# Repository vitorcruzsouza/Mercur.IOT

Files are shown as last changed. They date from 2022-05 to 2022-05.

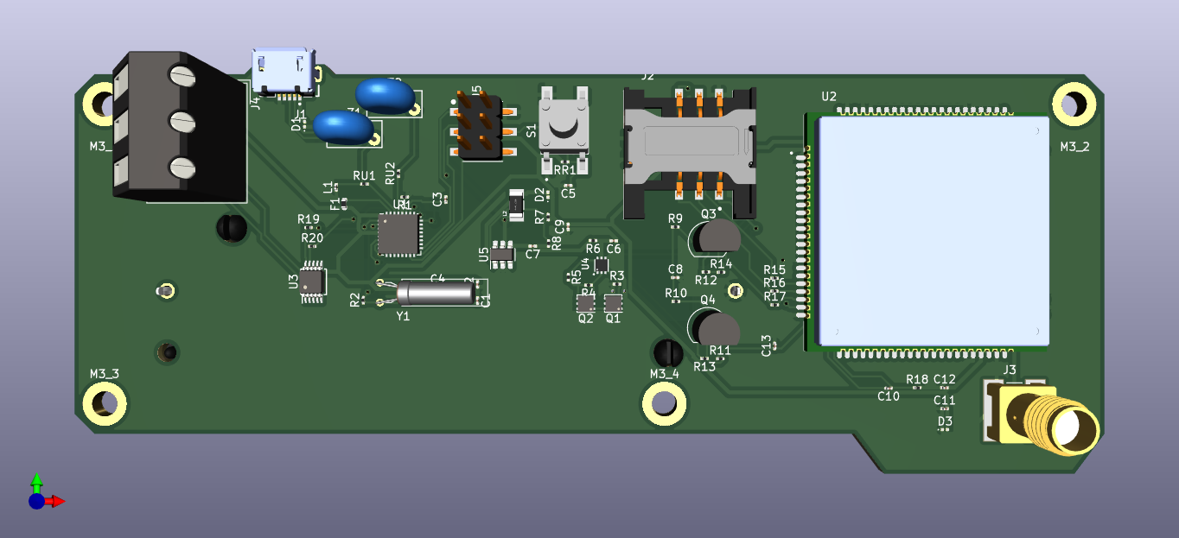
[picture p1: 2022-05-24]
docs/PCB_3D_top.png

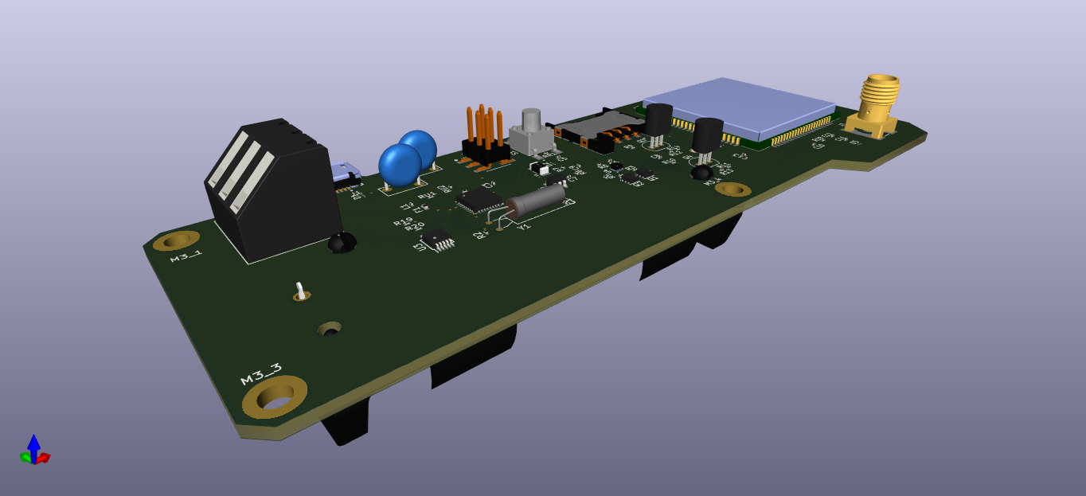
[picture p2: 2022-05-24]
docs/PCB_3D_isometric.png

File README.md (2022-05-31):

EN-US: This content was written in both English and Portuguese. To access content in English, [clique here](#enus)

PT-BR: Este conteúdo foi escrito em Inglês e em Português. Para acessar o conteúdo em Português, [clique aqui](#ptbr)

---

# EN/US
# MercurIOT - Sensor Data Transmitter via GSM
readme v1.6

## Contents

<!-- toc -->

- [1. Description](#description)
  - [Objective](#objective)
  - [Behind the name](#behind-the-name)
- [2. Plataform](#platform)
  - [Conceptualization - Electronics](#conceptualization---electronics)
  - [Conceptualization - Code](#conceptualization---code)
  - [Technical Specifications](#technical-specifications)
  - [Bill of Materials](#bill-of-materials)
- [3. Circuit Schematic](#circuit-schematic)
  - [Full System](#full-system)
  - [Power Supply](#power-supply-and-battery-charging)
  - [Microcontroller](#microcontroller)
  - [GSM Communication](#gsm-communication)
  - [Sensor 16-bit ADC](#sensor-16bit-adc)
- [4. Printed Circuit Board (PCB)](#printed-circuit-board-pcb)
  - [2D Visualization of All Layers](#2d-visualization-of-all-layers)
  - [2D Visualization of Top Layer](#2d-visualization-of-top-layer)
  - [2D Visualization of Bottom Layer](#2d-visualization-of-bottom-layer)
- [5. 3D Render of the PCB](#3d-render-of-the-pcb)
  - [Top View](#top-view)
  - [Bottom View](#bottom-view)
  - [Isometric View](#isometric-view)

- [About me](#about-me)

<!-- tocstop -->

## Description

#### Objective
Fully developing a wireless data transmission solution for industrial applications, capable of sending 500kB of sensing data remotely to be used in machine operation conditions monitoring.

The scope of this project encopasses the development of both the PCB and firmware required for operation of the microcontrollers utilized.

#### Behind the name
Inspired by the greek god Mercury, son of Zeus and messenger of the gods, MercurIOT was developed with the purpose of delivering a flexible platform, upon which multiple IOT communication solutions can be created.

## Platform 

### Conceptualization - Electronics:

To send sensor information to a distant receiver, the **GSM tecnology** was selected - the same used for 3G/4G mobile data plans - due to the ease of access to nacional brazillian infrastructure to mobile network systems (where this project was conceived), thus high capacity for long distance tranmissions.

Therefore, the **SIM7600EH** GSM communication chip was chosen, since it presents an easy to use yet powerful list of commands, high market availability and broad documentation.

For controlling the whole system and being responsible for converting the sensor data into commands the SIM7600 can understand, the Atmel **ATMEGA8U2-MU** was selected as a suitable microcontroller. Aside from having very broad documentation and market availability for being one the chips used by Arduino boards, the ATMEGA8 is specially handy for having integrated USB communication, simplifying the final board layout. Its 16MHz clock shall be sufficient to execute all of the communication with no major delays.

One of the limitations of the ATMEGA8, however, is the relatively low resolution of its ADC (Analog to Digital Converter chip), which has a 10 bit resolution (maximum of 1024 individual values in any readings). Therefore, an accompanying **ADS1115** chip was selected to improve the data quality the MercurIOT board can supply. This IC has a 16 bit resolution (max. 65,536 values) for analog readings, it can communicate in I2C protocol with other chips in its network, and can support up to 4 individual analog inputs. For this project, however, we're only going to use one.

Finally, to power the whole system, a **18650 Lithium-Ion** cell was selected, since this type of battery chemistry is very common and is currently one of the best options on Power Density to Price and/or size. Utilizing Li-Ion cells in this project allows it to be recharged, but adds a degree of complexity by requiring some battery monitoring and protection features. For this, the **BQ29707DSET** battery management IC is being used (features include overcharge protection, overdischarge protection, overcurrent protection) in conjunction with the **MT3608** boost-converter for stabilizing a 5VDC supply rail to all other electronics.

### Conceptualization - Code:

To construct a wireless transmission solution, there are a few major things that have to be considered. The first is what information is going to be sent, the second is how it is going to be sent, and third but not least how it is going to be interpreted by what's receiving it.

This way, the first problem that need to be tackled is the **information source** itself. In this project, for demonstration purposes, a hypothetical, unspecified, pre-amplified analog sensor is going to be used, as this is encopasses almost any type of application that telemetry sensors can be used in, since most physical quantity sensing devices output analog (voltage or current) signals.

Since a 16-bit capabe Analog to Digital Converter (ADC) is being used to capture these sensed signals, these 16-bit values have to be processed accordingly. For that, the Adafruit_ADS1015.h library is used, to facilitate I2C communication between the microcontroller and the ADC unit and to interpret the information.

Assuming a server is going to receive sensed data and utilize it, this processed information need to be sent via some medium. For this, the SIM7600EH chip has a list of GSM commands to perform varying tasks. If sent from the microcontroller to the GSM IC via serial UART communication, these commands will each perform an action through the 3G/4G communication line. [Here's a full list of AT commands and instructions on how to use them here.](https://usermanual.wiki/Document/SIM7500SIM760020SeriesAT20Command20ManualV107.443047306/html)

The information that is going to be transmitted, however, needs to be encoded in a certain protocol, so that both parties of this system - client (transmitter) and server (receiver) - can understand what is being relayed; and more critically, know what to do with each information given.

For this, the MQTT (Message Queuing Telemetry Transport) is used. It is a protocol based on TCP/IP network communication that simplifies parallel data transmission between multiple parties, specially for IoT applications such as this one, while providing a light and simple framework for less powerful devices to run on. [Read this for more information on how the MQTT protocol works.](https://randomnerdtutorials.com/what-is-mqtt-and-how-it-works/)

Joining the AT (GSM) and MQTT communication formats, we can compile the data collected by whichever sensor is plugged into the MercurIOT transmitter, and send it to a MQTT topic dedicated to captured sensor data, which then can be subscribed to by any software or BI (Business Inteligence) suite that whishes to utilize or display that information.

### Technical Specifications

#### Electronics

##### Control
- Microcontrolador: ATmega8U2-MU
- IC USB Communication: ATmega8U2-MU
- IC GSM Communication: SIM7600E-H
##### Power supply
- IC Battery Management: BQ29707DSET
- IC Voltage Regulator: MT3608
- Battery: Li-Ion 18650 cell
##### Sensing
- IC 16-bits Analog-Digital Converter: ADS1115

#### Code
- Library Adafruit_ADS1015.h (for I2C communication with the 16bit ADC)
- Library SoftwareSerial.h (for serial UART communication with the GSM and MQTT)
- Libraries Arduino.h, Wire.h e ArduinoLowPower.h (for using the native Arduino platform functionalities)
##### Software
- Development Environment: VSCode
- Platform: Plaform.io

### Bill of Materials

[Link to the Bill of Materials file, complete with links for ordering the parts used globally.](https://github.com/vitorcruzsouza/Mercur.IOT_TRACTIAN/blob/main/docs/BOM.md)

## Circuit Schematic
[Link to folder with circuit and PCB ECAD files.](https://github.com/vitorcruzsouza/Mercur.IOT_TRACTIAN/tree/main/hardware_sch/Mercurio_wirelessTransmitter)

### Full System
[Link to the full schematic file.](https://github.com/vitorcruzsouza/Mercur.IOT_TRACTIAN/blob/main/docs/Mercurio_SCHEMATIC-SHEET.pdf)
circuit_fullTransmitter

### Power Supply and Battery Charging
circuit_powerSupply

The circuit above utilizes a BQ2970 battery management IC to monitor the lithium-ion battery's voltage and offer multiple protections. By utilizing a selection of multiple internal comparators, the IC monitors the voltage coming from the positive side of the battery through the "BAT" pin 5. Either when the voltage is too high (±4.2V), too low (±3.4V) or the current is too high (overcurrent or short-circuit), the IC deactivates of its "COUT" or "DOUT" outputs to disconnect the battery's negative side to Ground, through its two CSD16301Q2 MOSFET switches.

Through the use of the MT3608 boost converter IC, both the battery's and the USB port's voltage are steped-up and regulated to 5VDC, for supplying both the ATMEGA and the SIM7600 chips. By using a zener diode between the USB port and the battery, as well as one between the boost converter an all of the componentes supplied, the circuit can be both powered on by the USB port and charge the battery simultaneously without causing a power loop.

### Microcontroller
circuit_microcontroller

Together with the microcontroller are a couple of passive components to allow its basic functioning, like a 16MHz clock crystal and accompanying oscillating capacitors, varistors for USB power protection and a ferrite bead for filtering, a 500mA fuse between the power circuit and the VCC port of the ATMEGA chip, a RESET button and 6 open pins (ICSP) for connecting configuration signals, such as boot loading and resetting once again.

### GSM Communication
circuit_GSM

In this schematic, two S8050 transistors can be observed in series with the TXD and RXD transmission lines that are used to connect the SIM7600E-H and the ATMEGA8U-MU via UART. This is used to decouple both chips while no data is being transmitted, since the very TXD and RXD lines activate the transistors that let the data bits pass, so that these wires do not act as antennas and pickup any interference, stopping any of the two ICs accidentally interpret noise as information.

Pins 17 - 20 are connected to the SIM card slot and therefore the SIM card inserted, and pin 82 is connected to a SMA antenna connector, so that any type or size of antenna desired can be used.

The "PWRKEY" and "RESET" are pulled to ground so that the IC is always active. One improvement this circuit design could benefit from is having the microcontroller, via a switching device, have the option to activate or deactivate both the Reset and Power-Key pins so that the IC can be rebooted or turned off completely for power saving measures.

### Sensor 16bit ADC
circuit_ADC

Last but not least, the ADS1115 16-bit ADC is connected to the SCL and SCA pins of the ATMEGA microcontroller, through which the ADC relays the sensed analog  signals through I2C serial communication. The sensor, whichever one may be chosen for the application, can be connected to the J4 screw terminal following the "VCC, Signal, GND" pinout standard.

## Printed Circuit Board (PCB)

### 2D Visualization of All Layers
PCB_2D_all-layers

For information all data lines excluding the antenna line, the traces were set to 10 mils (0.254 mm). For all other lines (power lines and antenna), the traces were set to 20 mils (0.5 mm), so that a maximum of 1.5 A can be supplied to all components and used for more power-intensive LTE data transmission.

### 2D Visualization of Top Layer
PCB_2D_top-layer

### 2D Visualization of Bottom Layer
PCB_2D_bottom-layer

## 3D Render of the PCB

### Top View
PCB_3D_top

### Bottom View
PCB_3D_bottom

### Isometric View
PCB_3D_isometric

## About me

### Contact info:
<p>Vitor Cruz Souza<br>
São Paulo, SP, Brazil<br>
E-mail: vitor.cruz.souza.2001@gmail.com</p>

---

[Back to the top.](#contents)

---

# PT/BR
# MercurIOT - Transmissor de Dados de Sensor via GSM
readme v1.52

(Esta sessão ainda não foi totalmente traduzida).

## Conteúdos

<!-- toc -->

- [1. Descrição](#descrição)
  - [Objetivo](#objetivo)
  - [Por trás do nome](#por-trás-do-nome)
- [2. Plataforma](#plataforma)
  - [Conceitualização](#conceitualização)
  - [Especificações Técnicas](#especificações-técnicas)
  - [Lista de Materiais](#lista-de-materiais)
- [3. Esquemático do Circuito](#esquemático-do-circuito)
  - [Sistema Completo](#sistema-completo)
  - [Alimentação e Bateria](#alimentação-e-bateria)
  - [Microcontrolador](#microcontrolador)
  - [Comunicação GSM](#comunicação-gsm)
  - [ADC 16bits do Sensor](#adc-16bits-do-sensor)
- [4. Placa de Circuito Impresso (PCI)](#placa-de-circuito-impresso-pci)
  - [Visualização 2D de Todas as Camadas](#visualização-2d-de-todas-as-camadas)
  - [Visualização 2D da Camada Superior](#visualização-2d-da-camada-superior)
  - [Visualização 2D da Camada Inferior](#visualização-2d-da-camada-inferior)
- [5. Renderização 3D da PCI](#renderização-3d-da-pci)
  - [Vista Superior](#vista-superior)
  - [Vista Inferior](#vista-inferior)
  - [Vista Isométrica](#vista-isométrica)

- [Sobre mim](#sobre-mim)

<!-- tocstop -->

## Descrição

#### Objetivo
O objetivo do projeto MercurIOT é desenvolver uma solução completa de transmissão de dados para aplicações industriais, capaz de enviar 500kB de dados de sensoriamento remotamente, a serem usados no monitoramento de condições de operação de máquinas.

O escopo deste projeto abriga o desenvolvimento de ambos PCI e firmware necessário para operação dos microcontroladores utilizados.

#### Por trás do nome
Inspirado no deus greco-romano Mercúrio, filho de Zeus e mensageiro dos deuses, o MercurIOT foi desenvolvido com o propósito de entregar uma plataforma flexível, sobre a qual múltiplas soluções de comunicação IOT possam ser criadas.

## Plataforma

### Conceitualização

Para realizar o envio de informações do sensor à distância, foi escolhido utilizar de tecnologia GSM, a mesma utilizada para comunicação 3G/4G em telefonia móvel, devido ao fácil acesso à infraestrutura nacional brasileira de redes móveis (onde este projeto foi concebido) e, portanto, alta capacidade de transmissão de dados à longas distâncias.

### Especificações Técnicas

#### Eletrônica

##### Controle
- Microcontrolador: ATmega8U2-MU
- CI Comunicação USB: ATmega8U2-MU
- CI Comunicação GSM: SIM7600E-H
##### Alimentação
- CI Gerenciamento de Baterias: BQ29707DSET
- CI Regulador de Tensão: MT3608
- Bateria: Li-Ion 18650
##### Sensoriamento
- CI Conversor Analógico Digital 16-bits: ADS1115

#### Código
- Biblioteca Adafruit_ADS1015.h (para comunicação I2C com o ADC de 16bits)
- Biblioteca SoftwareSerial.h (para comunicação serial UART com o GSM e MQTT)
- Bibliotecas Arduino.h, Wire.h e ArduinoLowPower.h (para uso de funcionalidades nativas da plataforma Arduino)

##### Software
- Ambiente de Desenvolvimento: VSCode
- Plataforma: Plaform.io

### Lista de Materiais

[Link para a Lista de Materiais contendo também links para compra internacional dos componentes usados.](https://github.com/vitorcruzsouza/Mercur.IOT_TRACTIAN/blob/main/docs/BOM.md)

## Esquemático do Circuito
[Link para pasta com arquivos ECAD do circuito e PCB.](https://github.com/vitorcruzsouza/Mercur.IOT_TRACTIAN/tree/main/hardware_sch/Mercurio_wirelessTransmitter)

### Sistema Completo
[Link para o arquivo do esquemático completo.](https://github.com/vitorcruzsouza/Mercur.IOT_TRACTIAN/blob/main/docs/Mercurio_SCHEMATIC-SHEET.pdf)
circuit_fullTransmitter

### Alimentação e Bateria
circuit_powerSupply

### Microcontrolador
circuit_microcontroller

### Comunicação GSM
circuit_GSM

### ADC 16bits do Sensor
circuit_ADC

## Placa de Circuito Impresso (PCI)
[Link para pasta com arquivos ECAD do circuito e PCB.](https://github.com/vitorcruzsouza/Mercur.IOT_TRACTIAN/tree/main/hardware_sch/Mercurio_wirelessTransmitter)

### Visualização 2D de Todas as Camadas
PCB_2D_all-layers

### Visualização 2D da Camada Superior
PCB_2D_top-layer

### Visualização 2D da Camada Inferior
PCB_2D_bottom-layer

## Renderização 3D da PCI

### Vista Superior
PCB_3D_top

### Vista Inferior
PCB_3D_bottom

### Vista Isométrica
PCB_3D_isometric

## Sobre mim

### Informações de contato:
<p>Vitor Cruz Souza<br>
São Paulo, SP, Brasil<br>
E-mail: vitor.cruz.souza.2001@gmail.com</p>

---

[Ir para o topo.](#conteúdos)

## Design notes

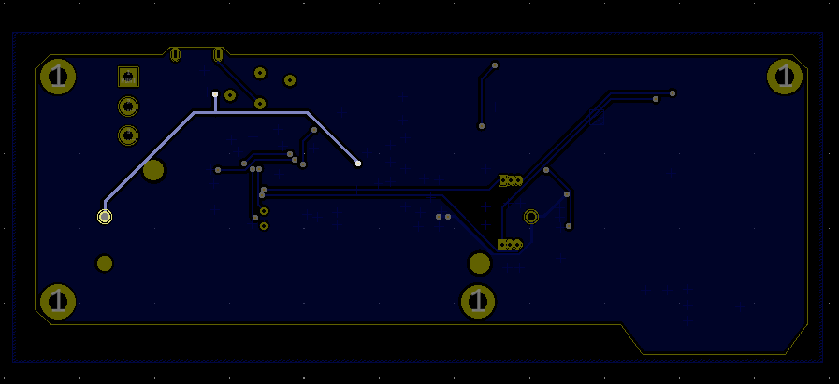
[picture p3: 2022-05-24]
docs/PCB_2D_bottom-layer.png

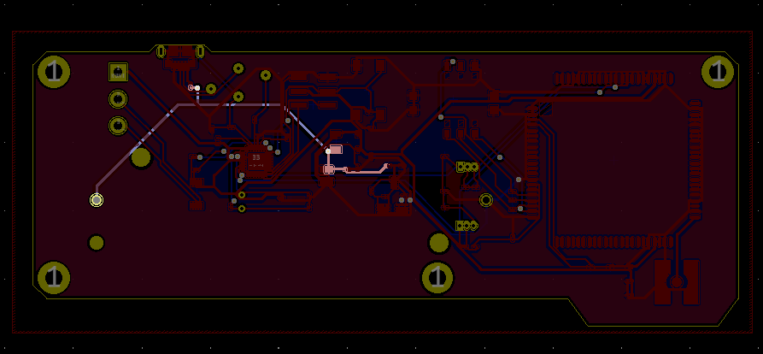
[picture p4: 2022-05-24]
docs/PCB_2D_all-layers.png

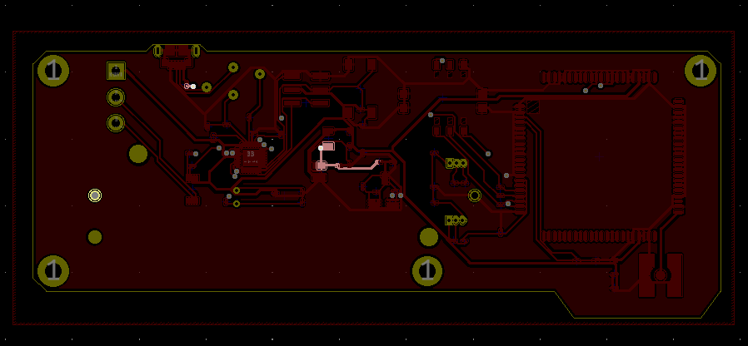
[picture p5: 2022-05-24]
docs/PCB_2D_top-layer.png

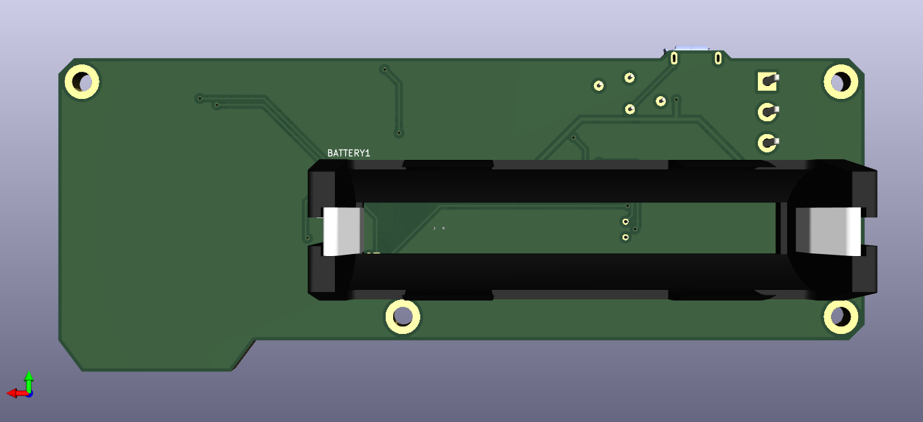
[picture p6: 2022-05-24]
docs/PCB_3D_bottom.png

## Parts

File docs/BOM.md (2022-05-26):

# Bill of Materials (BOM)

| Nº | COMPONENT                | PART Nº            | VALUE             | PACKAGE    | QTY | DESIGNATOR           | REFERENCE                                                                                                                                                                                     |
| Nº | COMPONENT                | PART Nº            | VALUE             | PACKAGE    | QTY | DESIGNATOR           | REFERENCE                                                                                                                                                                                     |
| -- | ------------------------ | ------------------ | ----------------- | ---------- | --- | -------------------- | ------ |
| 1  | Socket for 18650 Battery | 1043               | \-                | Custom     | 1   | BATTERY1             | https://www.mouser.com/ProductDetail/Keystone-Electronics/1043?utm\_campaign=mouser&qs=%2F7TOpeL5Mz6j%2FnxeOA1rsg%3D%3D&utm\_content=model&utm\_medium=online&utm\_source=snapedaonline       |
| 2  | Capacitor SMD            | LD033D105MAB2A     | 1uF               | SMD 0603   | 2   | C3, C13              | https://www.digikey.com/en/products/detail/kyocera-avx/LD033D105MAB2A/11235553?utm\_medium=aggregator&utm\_campaign=buynow&utm\_source=snapeda                                                |
| 3  | Capacitor SMD            | 885012206046       | 100nF             | SMD 0603   | 1   | C4                   | https://www.mouser.com/ProductDetail/Wurth-Elektronik/885012206046?utm\_medium=online&utm\_source=snapedaonline&utm\_content=model&utm\_campaign=mouser&qs=0KOYDY2FL2%252B89gr6HvTBXA%3D%3D   |
| 4  | Capacitor SMD            | C0603C104J4RACTM   | 0.1uF             | SMD 0603   | 5   | C5, C6, C8, C10, C11 | https://www.mouser.com/ProductDetail/KEMET/C0603C104J4RACTM?utm\_medium=online&utm\_source=snapedaonline&utm\_content=model&utm\_campaign=mouser&qs=dtFCtVqVXWcMSWNKXNx%2FXw%3D%3D            |
| 5  | Capacitor SMD            | C1608JB0J226M080AC | 22pF              | SMD 0603   | 2   | C1, C2, C7, C9       | https://www.mouser.com/ProductDetail/TDK/C1608JB0J226M080AC?utm\_medium=online&utm\_source=snapedaonline&utm\_content=model&utm\_campaign=mouser&qs=xLDY6iXSiQbnuIg2qX8hLQ%3D%3D              |
| 6  | Capacitor SMD            | 06033A330KAT2A     | 33pF              | SMD 0603   | 1   | C12                  | https://www.mouser.com/ProductDetail/Kyocera-AVX/06033A330KAT2A?utm\_campaign=mouser&qs=3M9tbN%252BqtAY8x5rz2c8b4A%3D%3D&utm\_content=model&utm\_medium=online&utm\_source=snapedaonline      |
| 7  | Diode SMD                | MMSZ5221B          | \-                | SOD-123F   | 3   | D1-D3                | https://www.digikey.com/en/products/detail/taiwan-semiconductor-corporation/MMSZ5221B-RHG/7374840?utm\_medium=aggregator&utm\_campaign=buynow&utm\_source=snapeda                             |
| 8  | Fuse SMD                 | 0603L050SLYR       | 500mA             | SMD 0603   | 1   | F1                   | https://www.mouser.com/ProductDetail/Littelfuse/0603L050SLYR?utm\_medium=online&utm\_campaign=mouser&qs=%252BPPFKVzHyALE6NerVow6aQ%3D%3D&utm\_content=model&utm\_source=snapedaonline         |
| 9  | Connector USB Micro B    | USB3075-30-A       | \-                | SMD        | 1   | J1                   | https://www.mouser.com/ProductDetail/GCT/USB3075-30-A?utm\_campaign=mouser&qs=KUoIvG%2F9IlbGMJplbp1ybA%3D%3D&utm\_content=model&utm\_medium=online&utm\_source=snapedaonline                  |
| 10 | Socket for SIM Card      | 693010020611       | \-                | SMD        | 1   | J2                   | https://www.mouser.com/ProductDetail/Wurth-Elektronik/693010020611?utm\_campaign=mouser&qs=E2PpAYvlWVtRUX051C0QBA%3D%3D&utm\_content=model&utm\_medium=online&utm\_source=snapedaonline       |
| 11 | Socket for SMA Antenna   | CONSMA001          | \-                | THT        | 1   | J3                   | https://www.mouser.com/ProductDetail/Linx-Technologies/CONSMA001?utm\_medium=online&utm\_source=snapedaonline&utm\_content=model&utm\_campaign=mouser&qs=K5ta8V%252BWhtZcWpGVLKOC5A%3D%3D     |
| 12 | Terminal Block 1x3 5mm   | 30602              | \-                | THT        | 1   | J4                   | https://www.mouser.com/ProductDetail/Altech/30.602?qs=6YwAVAdATLxlHE0VSugUBQ%3D%3D                                                                                                            |
| 13 | Connector Header 6 Pins  | 61000621121        | \-                | THT        | 1   | J5                   | https://www.mouser.com/ProductDetail/Wurth-Elektronik/61000621121?utm\_campaign=mouser&qs=PhR8RmCirEYoFU9UUO%252Bbug%3D%3D&utm\_content=model&utm\_medium=online&utm\_source=snapedaonline    |
| 14 | Ferrite Bead SMD         | BLM21BD222TZ1D     | 2.2k Ohm 100MHz   | SMD 0603   | 1   | L1                   | https://www.mouser.com/ProductDetail/Murata-Electronics/BLM21BD222TZ1D?utm\_medium=online&utm\_source=snapedaonline&utm\_content=model&utm\_campaign=mouser&qs=lEfY3O89AqmiyVVAo6%2F2iA%3D%3D |
| 15 | Inductor SMD             | AIML-1206-120K-T   | 12uH              | SMD 1206-2 | 1   | L2                   | https://www.digikey.com/en/products/detail/abracon-llc/AIML-1206-120K-T/2663044?utm\_campaign=buynow&utm\_medium=aggregator&utm\_source=snapeda                                               |
| 16 | MOSFET N-channel         | CSD16301Q2         | \-                | WSON-6     | 2   | Q1, Q2               | https://www.mouser.com/ProductDetail/Texas-Instruments/CSD16301Q2?utm\_campaign=mouser&qs=6eIRK1XQNPbc2iRancB5Tw%3D%3D&utm\_content=model&utm\_medium=online&utm\_source=snapedaonline        |
| 17 | Transistor BJT NPN       | SS8050CTA          | \-                | TO-92      | 2   | Q3, Q4               | https://www.mouser.com/ProductDetail/onsemi-Fairchild/SS8050CTA?qs=UMEuL5FsraCvGU9pAIJ0vg%3D%3D                                                                                               |
| 18 | Resistor SMD             | MCT0603MD1004BP500 | 1M Ohm            | SMD 0603   | 1   | R1                   | https://www.mouser.com/ProductDetail/Vishay/MCT0603MD1004BP500?qs=Jslch3jnSjlxqHB2XifrNA%3D%3D                                                                                                |
| 19 | Resistor SMD             | CMP0603AFX-27R0ELF | 27 Ohm            | SMD 0603   | 1   | R2                   | https://www.mouser.com/ProductDetail/Bourns/CMP0603AFX-27R0ELF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                                                                              |
| 20 | Resistor SMD             | CR0603-JW-515ELF   | 5.1M Ohm          | SMD 0603   | 2   | R3, R4               | https://www.mouser.com/ProductDetail/Bourns/CR0603-JW-515ELF?qs=tknLyCMIRbNISwUtBrYwDA%3D%3D                                                                                                  |
| 21 | Resistor SMD             | CR0603-FX-2201ELF  | 2.2k Ohm          | SMD 0603   | 1   | R5                   | https://www.mouser.com/ProductDetail/Bourns/CR0603-FX-2201ELF?qs=zx2075yZkZKUzLkJq4yLqg%3D%3D                                                                                                 |
| 22 | Resistor SMD             | CMP0603-FX-3300ELF | 330 Ohm           | SMD 0603   | 1   | R6                   | https://www.mouser.com/ProductDetail/Bourns/CMP0603-FX-3300ELF?qs=TiOZkKH1s2TCw5ua2N2IJg%3D%3D                                                                                                |
| 23 | Resistor SMD             | CR0603-FX-2200ELF  | 220 Ohm           | SMD 0603   | 1   | R7                   | https://www.mouser.com/ProductDetail/Bourns/CR0603-FX-2200ELF?qs=zx2075yZkZJIjTIaFPYl8g%3D%3D                                                                                                 |
| 24 | Resistor SMD             | RCS060330R0FKEA    | 30 Ohm            | SMD 0603   | 1   | R8                   | https://www.mouser.com/ProductDetail/Vishay-Dale/RCS060330R0FKEA?qs=HalnxurKHBvY2IbBct5T7Q%3D%3D                                                                                              |
| 25 | Resistor SMD             | CRCW06034K70FKEAHP | 4.7k Ohm          | SMD 0603   | 2   | R9-R14               | https://www.mouser.com/ProductDetail/Vishay-Dale/CRCW06034K70FKEAHP?qs=k2%2FDWSARqgF9tclCHvhGkQ%3D%3D                                                                                         |
| 26 | Resistor SMD             | CHP0603AJW-220ELF  | 22 Ohm            | SMD 0603   | 4   | R15-R17, RU1, RU2    | https://www.mouser.com/ProductDetail/Bourns/CHP0603AJW-220ELF?qs=GedFDFLaBXEEl5eoX7Ig7w%3D%3D                                                                                                 |
| 27 | Resistor SMD             | CHP0603AFX-1001ELF | 1k Ohm            | SMD 0603   | 1   | R18                  | https://www.mouser.com/ProductDetail/Bourns/CHP0603AFX-1001ELF?qs=BJlw7L4Cy79wF3rZ%2FmXmqQ%3D%3D                                                                                              |
| 28 | Resistor SMD             | RCA060310K0FKEAHP  | 10k Ohm           | SMD 0603   | 3   | R19, R20, RR1        | https://www.mouser.com/ProductDetail/Vishay-Draloric/RCA060310K0FKEAHP?qs=rrS6PyfT74co7hzD7IqH8w%3D%3D                                                                                        |
| 29 | Switch SPST              | 5-1437565          | \-                | SMD        | 1   | S1                   | https://www.mouser.com/ProductDetail/Microchip-Technology/ATMEGA8U2-MU?qs=JV7lzlMm3yIasmzHjSeQNw%3D%3D                                                                                        |
| 30 | ATMEGA8 Microcontroller  | ATMEGA8U2-MU       | \-                | QFN-32     | 1   | U1                   | https://www.mouser.com/ProductDetail/Microchip-Technology/ATMEGA8U2-MU?qs=JV7lzlMm3yIasmzHjSeQNw%3D%3D                                                                                        |
| 31 | SIM7600 GSM IC           | SIM7600E-H         | \-                | Tray       | 1   | U2                   | https://www.digikey.com/en/products/detail/simcom-wireless-solutions-limited/SIM7600E-H/15841468?utm\_campaign=buynow&utm\_medium=aggregator&utm\_source=snapeda                              |
| 32 | ADS1115 ADC IC           | ADS1115IDGS        | \-                | VSSOP-10   | 1   | U3                   | https://www.mouser.com/ProductDetail/Texas-Instruments/ADS1115IDGSR?utm\_campaign=mouser&qs=IK5e5L0zOXjKCJoVMhYO%2FQ%3D%3D&utm\_content=model&utm\_medium=online&utm\_source=snapedaonline    |
| 33 | Battery Management IC    | BQ29707DSET        | \-                | WSON-6     | 1   | U4                   | https://www.mouser.com/ProductDetail/Texas-Instruments/BQ29707DSET?qs=7z%252BmIopC6%2FK8PFHAGER5Bg%3D%3D                                                                                      |
| 34 | Boost Converter IC       | MT3608             | \-                | SOT-23-6   | 1   | U5                   | https://lcsc.com/product-detail/DC-DC-Converters\_XI-AN-Aerosemi-Tech-MT3608\_C84817.html                                                                                                     |
| 35 | Crystal                  | AB308-16.000MHZ    | 16MHz             | THT        | 1   | Y1                   | https://www.mouser.com/ProductDetail/ABRACON/AB308-16.000MHZ?qs=GgB7MJ%2FTIsRBoegjtNv69g%3D%3D                                                                                                |
| 36 | Varistor                 | B72207S1390K201    | 50VDC 1.2kA 900pF | THT        | 2   | Z1, Z2               | https://www.mouser.com/ProductDetail/EPCOS-TDK/B72207S1390K201?qs=dEfas%2FXlABKmh0iq2keXQQ%3D%3D                                                                                              |

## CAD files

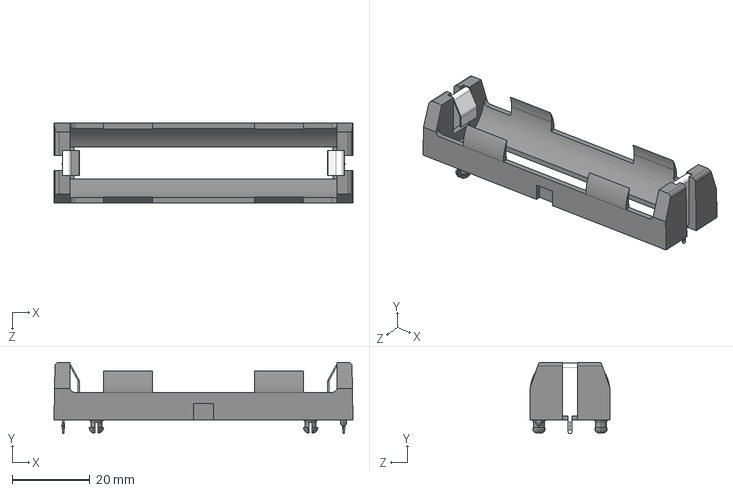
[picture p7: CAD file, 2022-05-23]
hardware_libs/1043/1043.step
77.1 x 18.4 x 20.7 mm

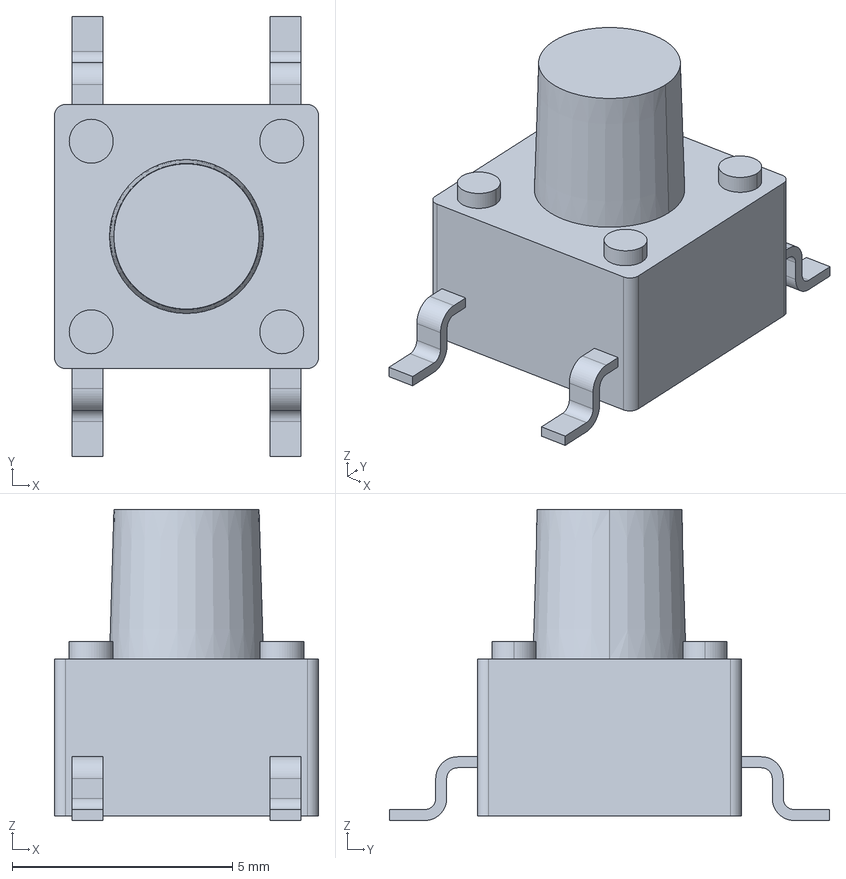
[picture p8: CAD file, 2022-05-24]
hardware_libs/5-1437565-0/5-1437565-0.step
6.00 x 10.0 x 7.07 mm

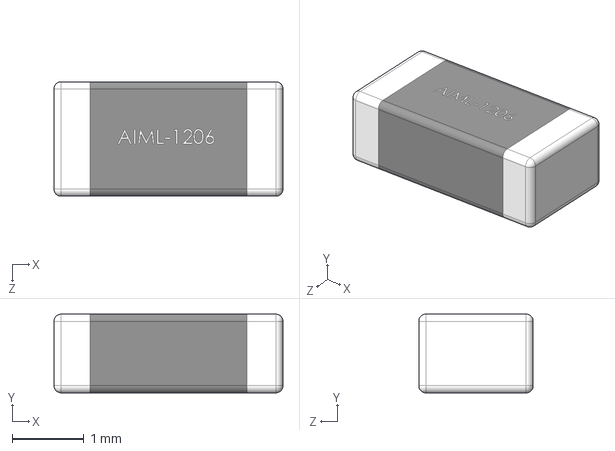
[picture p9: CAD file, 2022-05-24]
hardware_libs/AIML-1206-120K-T/AIML-1206-120K-T.step
3.20 x 1.10 x 1.60 mm

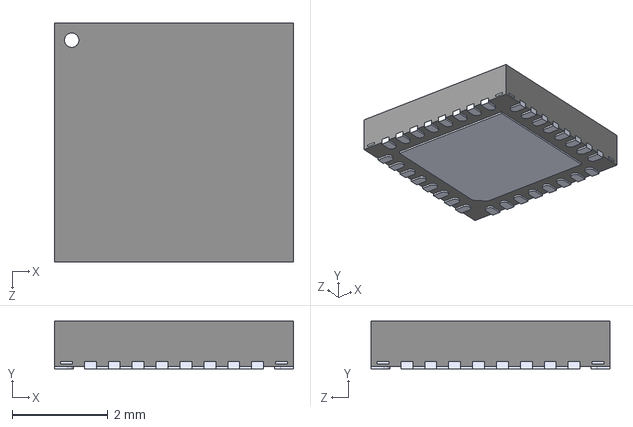
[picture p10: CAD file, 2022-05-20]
hardware_libs/ATMEGA8U2-MUR/ATMEGA16U2-MUR--3DModel-STEP-56544.STEP
5.00 x 1.00 x 5.00 mm

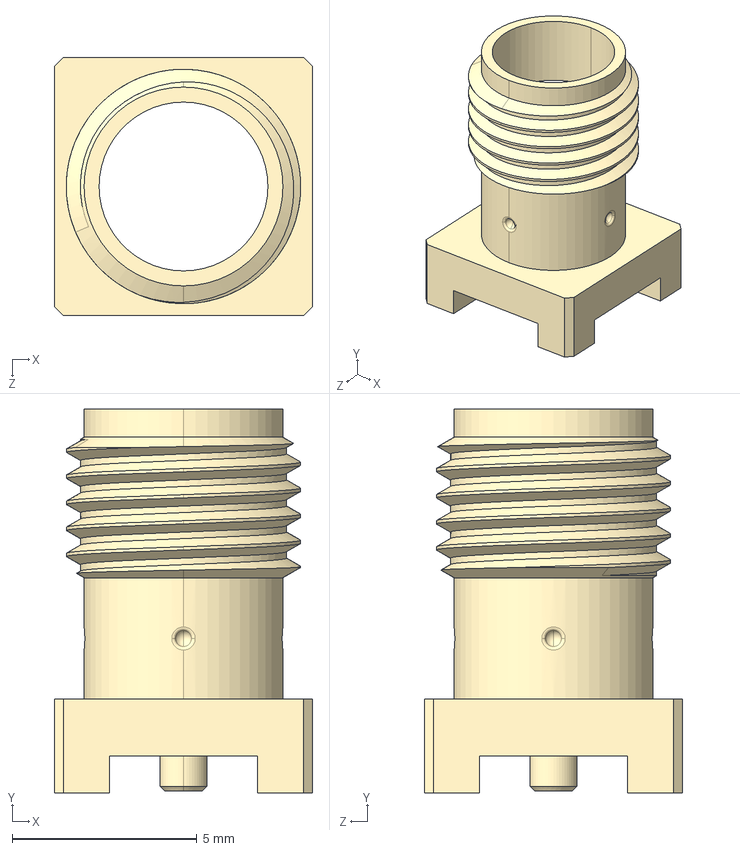
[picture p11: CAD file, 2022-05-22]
hardware_libs/CONSMA001-SMD-G/CONSMA001-SMD-G--3DModel-STEP-56544.STEP
7.00 x 10.4 x 7.00 mm

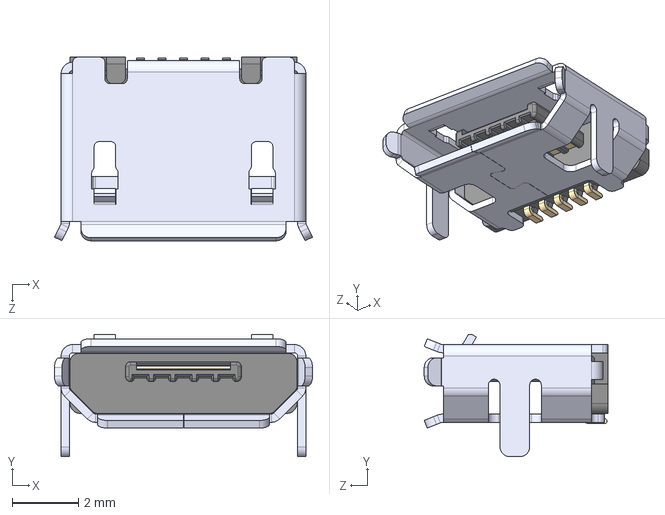
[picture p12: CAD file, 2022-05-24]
hardware_libs/USB3075-30-A/USB3075-30-A.step
7.80 x 3.70 x 5.55 mm

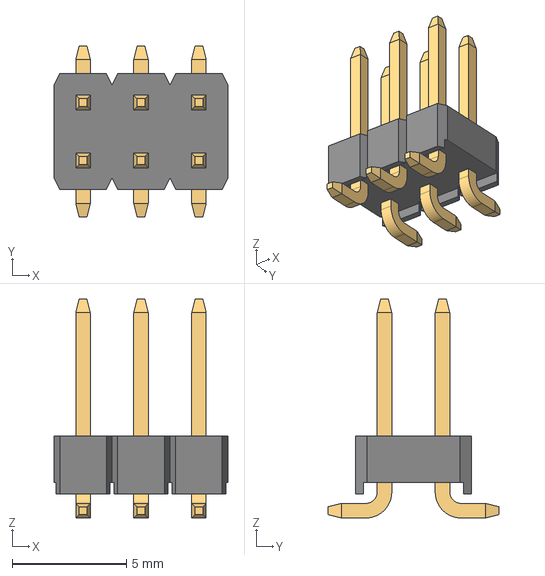
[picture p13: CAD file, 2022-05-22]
hardware_libs/61000621121/61000621121.step
7.62 x 7.50 x 9.60 mm

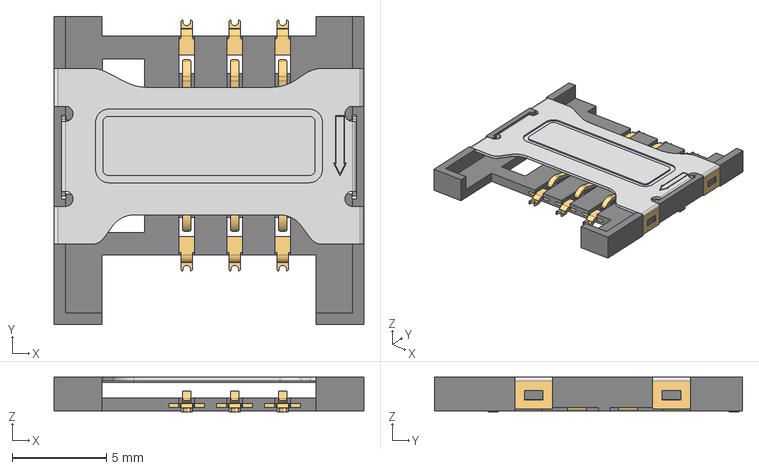
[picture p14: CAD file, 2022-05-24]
hardware_libs/693010020611/693010020611.step
16.4 x 16.3 x 1.85 mm

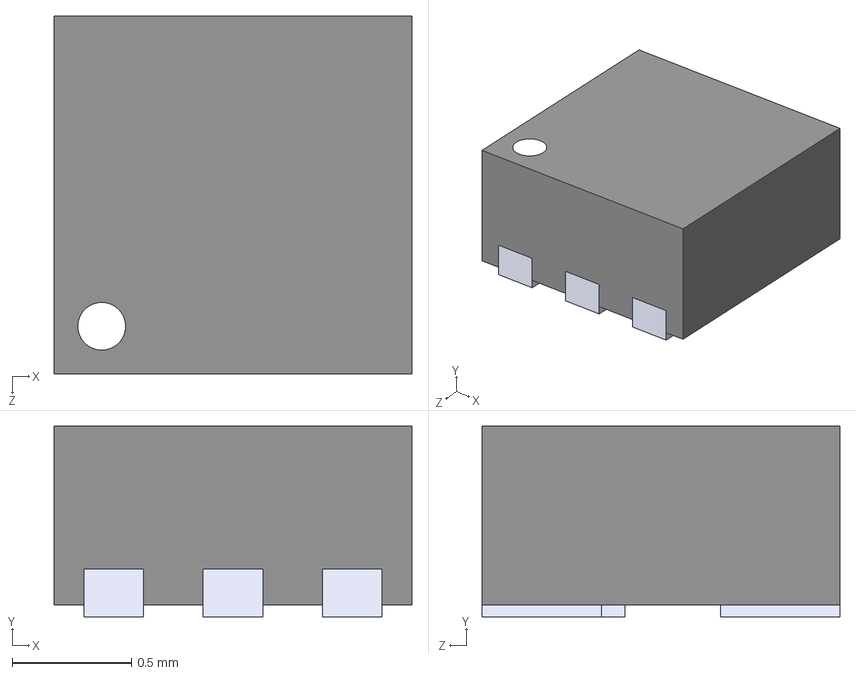
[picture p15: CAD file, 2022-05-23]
hardware_libs/BQ29707DSET/BQ29707DSET_1.STEP
1.50 x 0.8 x 1.50 mm

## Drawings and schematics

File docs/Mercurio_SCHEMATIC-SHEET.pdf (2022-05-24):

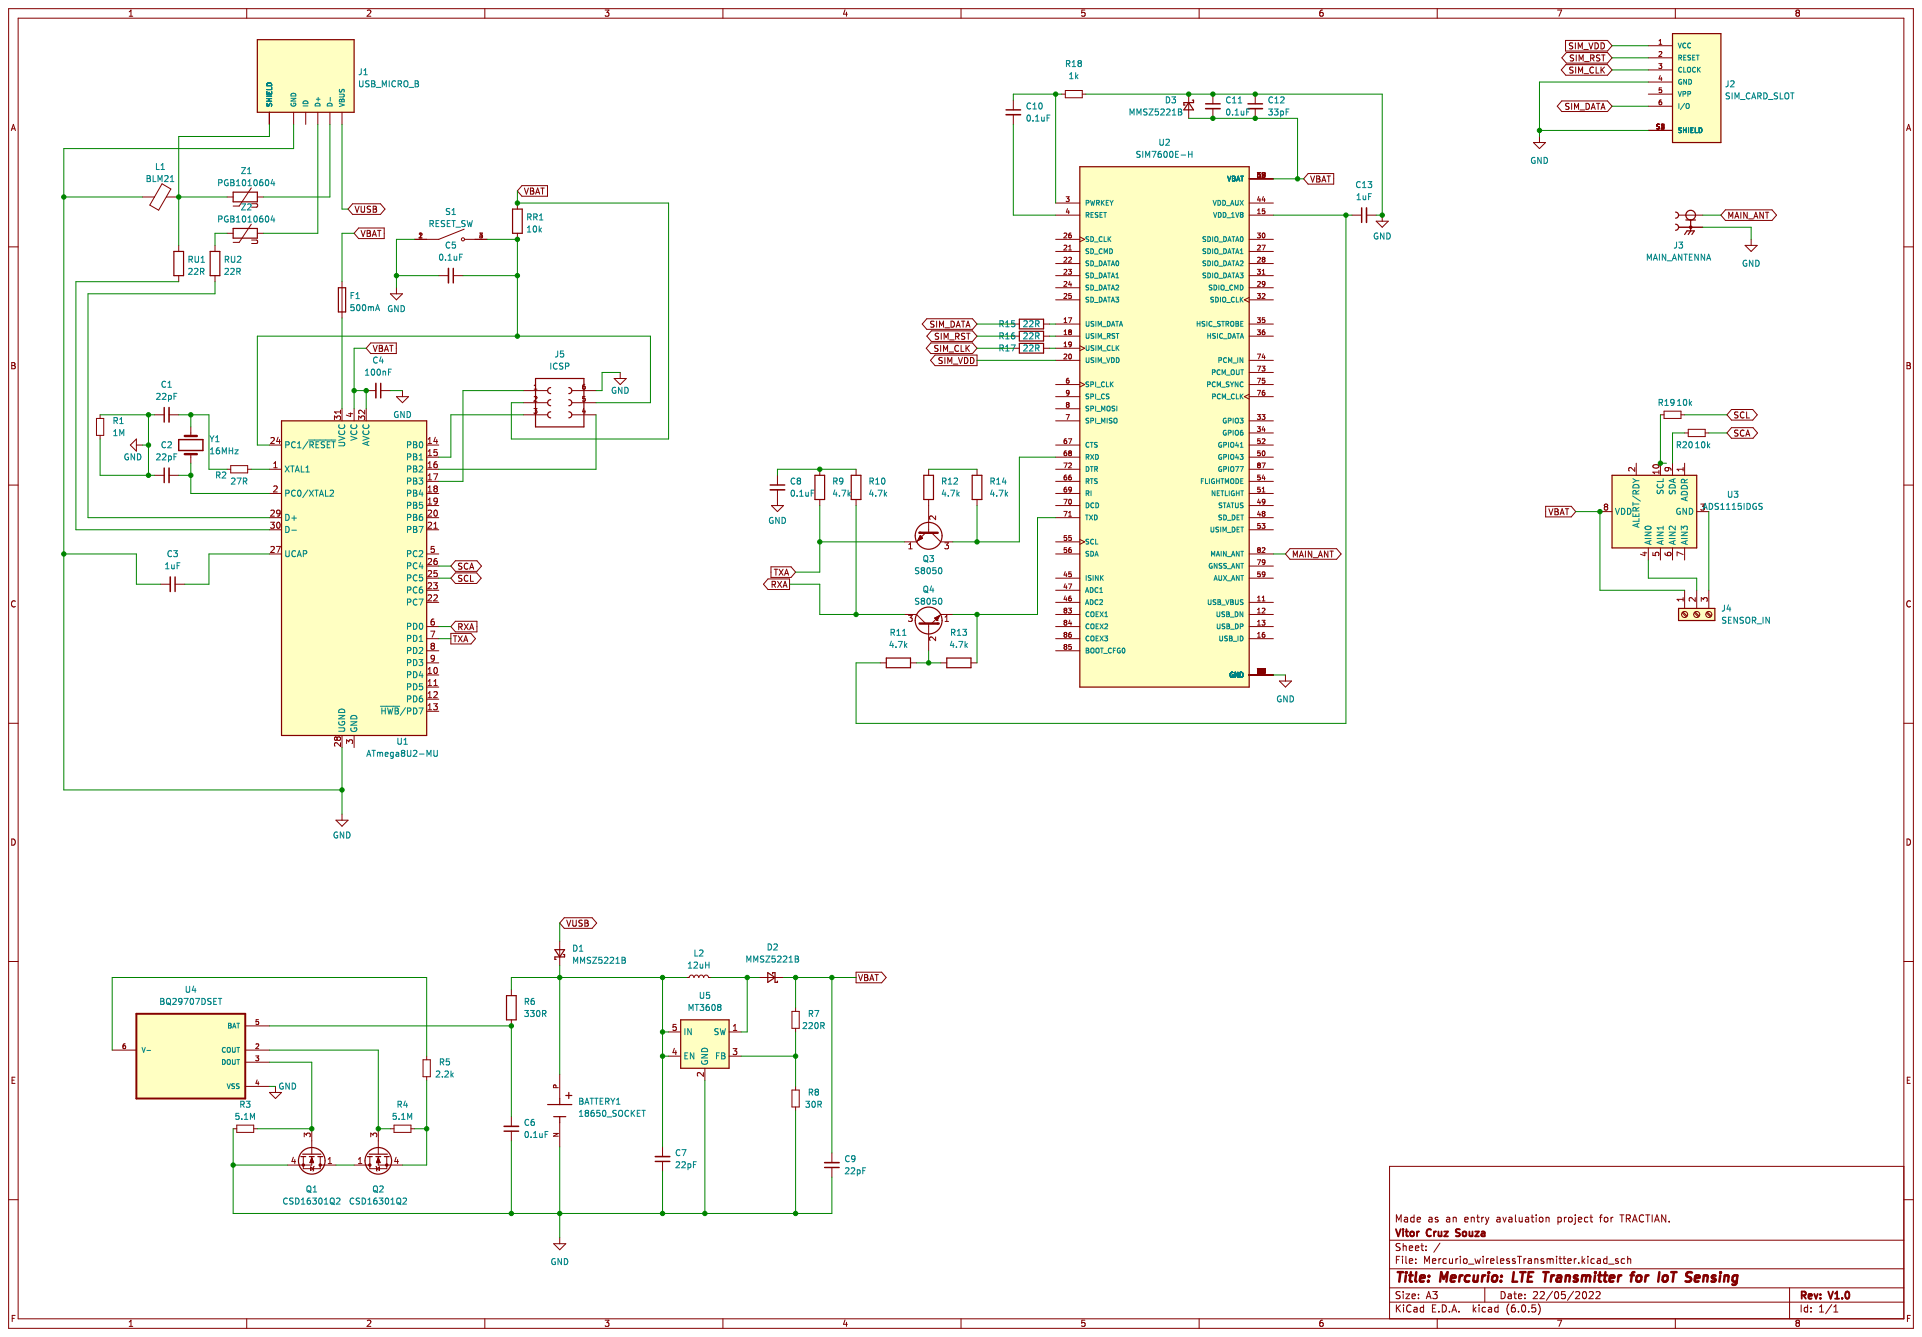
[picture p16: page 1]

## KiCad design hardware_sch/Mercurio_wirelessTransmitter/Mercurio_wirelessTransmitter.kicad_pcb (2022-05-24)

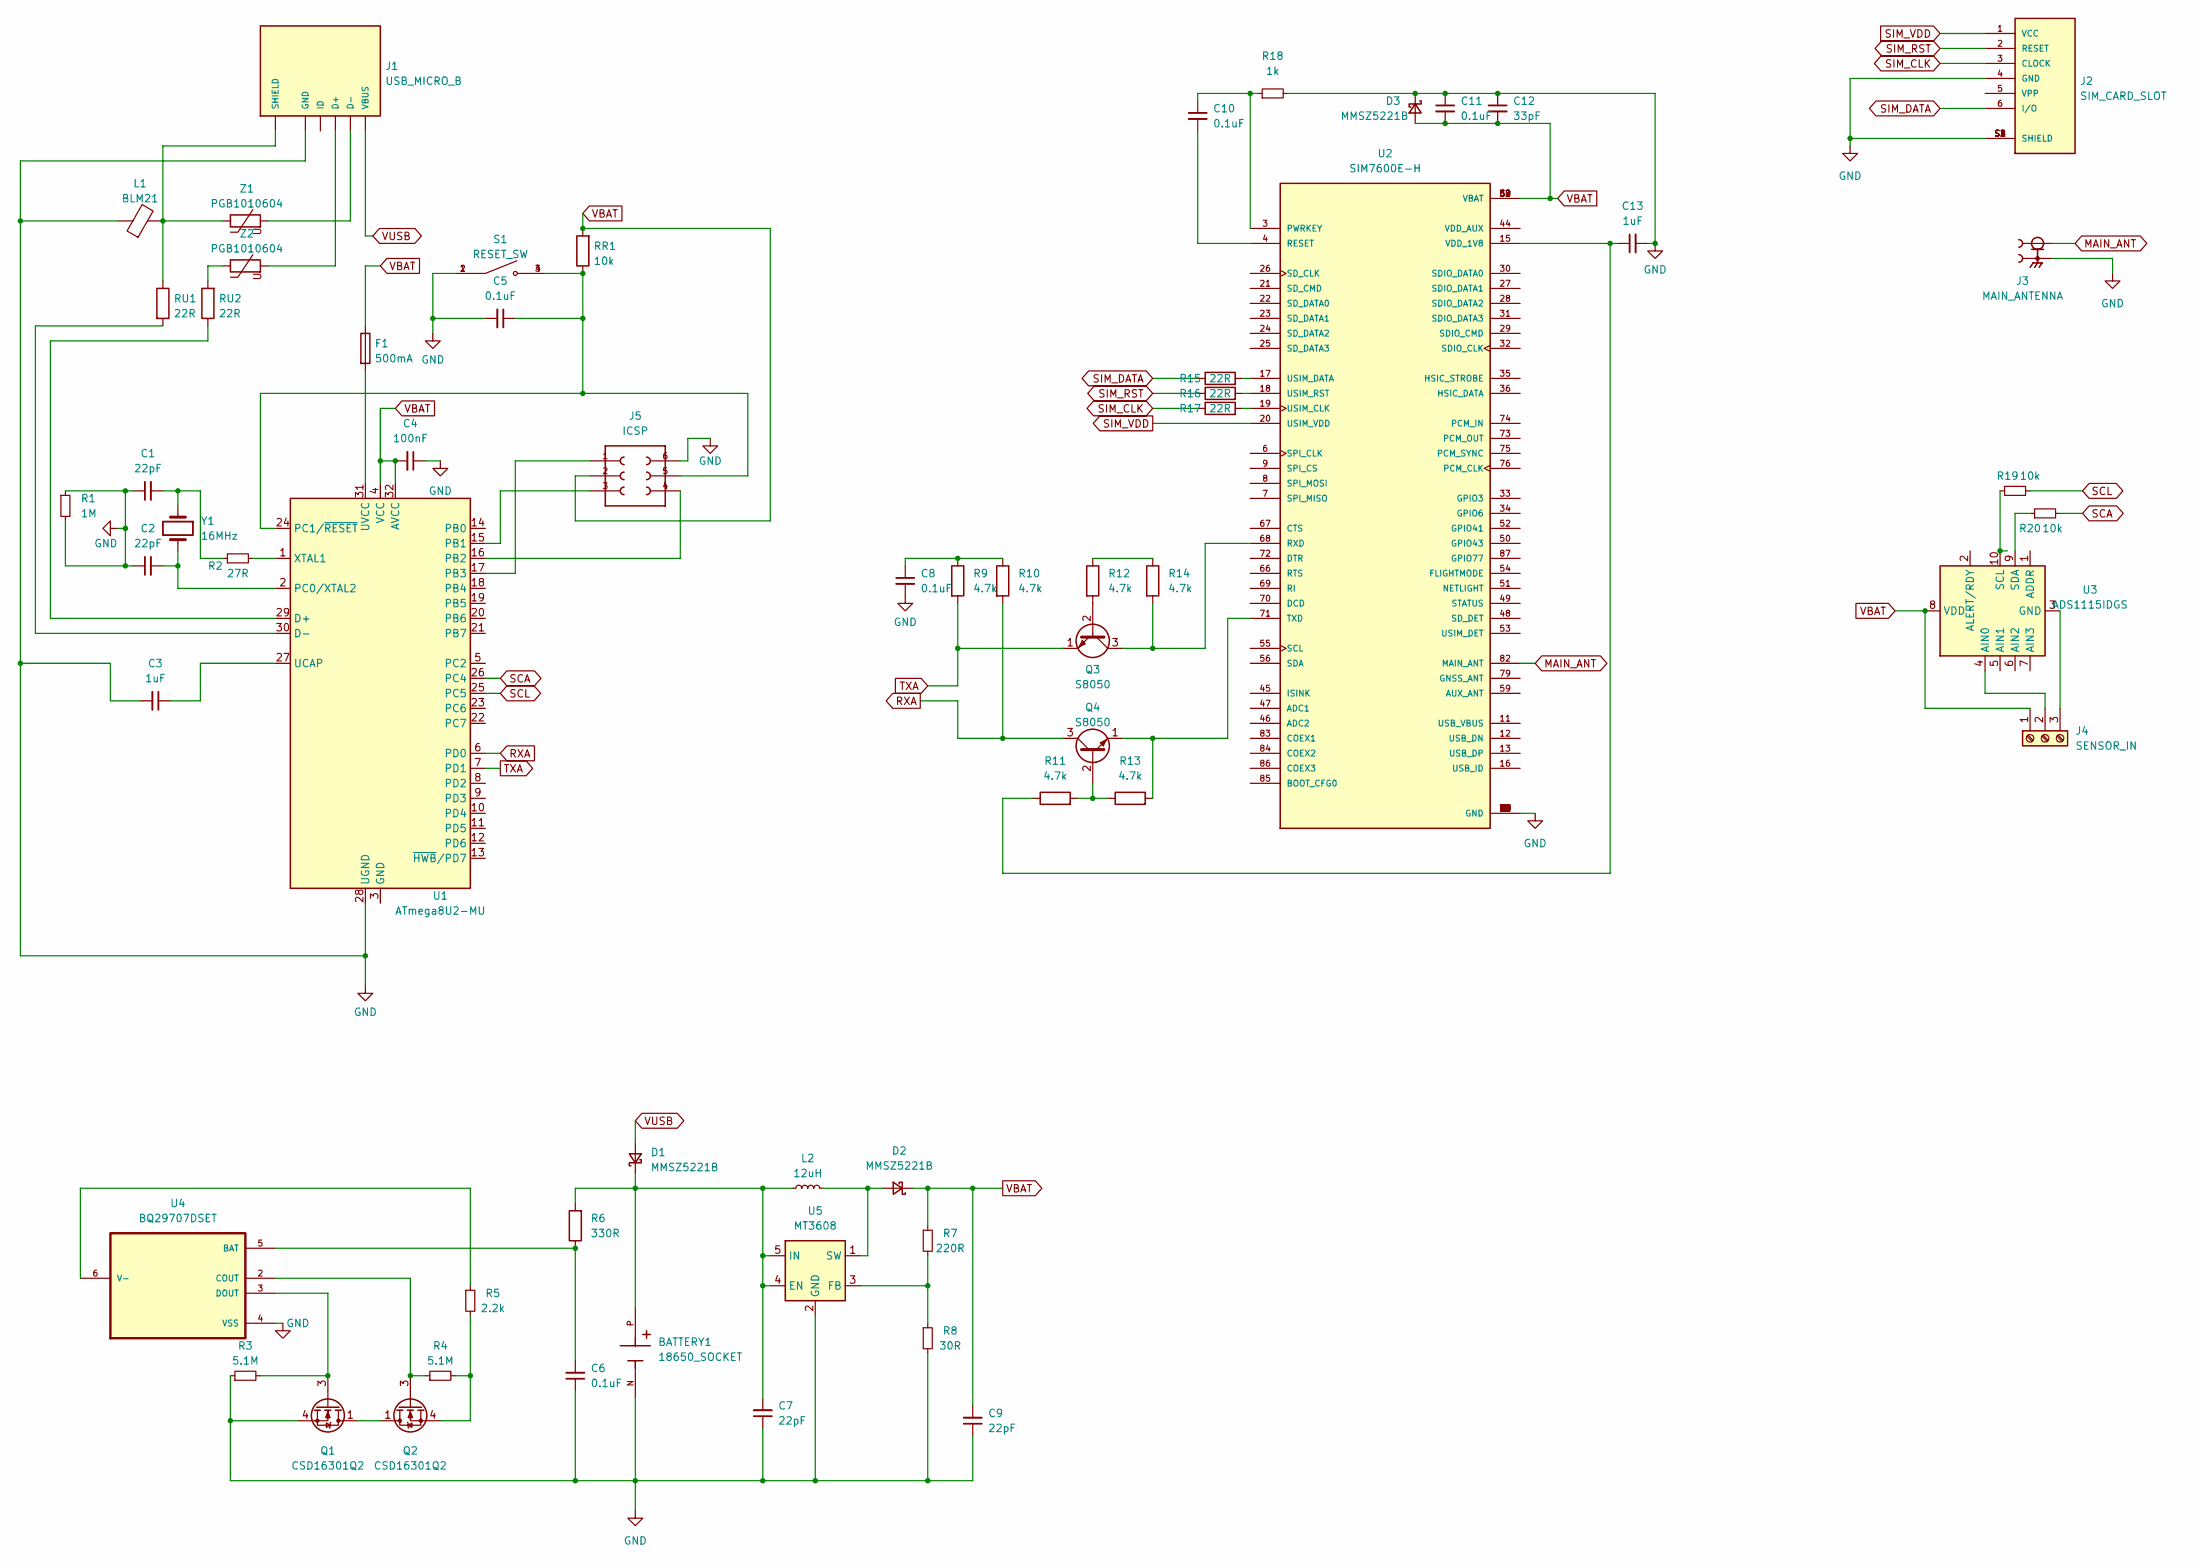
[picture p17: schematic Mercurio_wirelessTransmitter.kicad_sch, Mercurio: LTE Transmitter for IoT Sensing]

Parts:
BATTERY1: 18650_SOCKET; BAT_1043; PARTREV H
C1, C2, C7, C9: 22pF; C_0201_0603Metric
C3, C13: 1uF; C_0201_0603Metric
C4: 100nF; C_0201_0603Metric
C5, C6, C8, C10, C11: 0.1uF; C_0201_0603Metric
C12: 33pF; C_0201_0603Metric
D1, D2, D3: MMSZ5221B; D_0201_0603Metric
F1: 500mA; Fuse_0402_1005Metric
J1: USB_MICRO_B; GCT_USB3075-30-A; PARTREV D3
J2: SIM_CARD_SLOT; WURTH_693010020611; PARTREV F
J3: MAIN_ANTENNA; LINX_CONSMA001-SMD-G; PARTREV F
J4: SENSOR_IN; Altech_AK300_1x03_P5.00mm_45-Degree
J5: ICSP; 61000621121
L1: BLM21; L_0201_0603Metric
L2: 12uH; INDC3216X140N
Q1, Q2: CSD16301Q2; Texas_DQK
Q3, Q4: S8050; TO-92_Inline
R1: 1M; R_0201_0603Metric
R2: 27R; R_0201_0603Metric
R3, R4: 5.1M; R_0201_0603Metric
R5: 2.2k; R_0201_0603Metric
R6: 330R; R_0201_0603Metric
R7: 220R; R_0201_0603Metric
R8: 30R; R_0201_0603Metric
R9, R10, R11, R12, R13, R14: 4.7k; R_0201_0603Metric
R15, R16, R17: 22R; R_0201_0603Metric
R18: 1k; R_0201_0603Metric
R19, R20: 10k; R_0201_0603Metric
RR1: 10k; R_0201_0603Metric
RU1, RU2: 22R; R_0201_0603Metric
S1: RESET_SW; SW_5-1437565-0
U1: ATmega8U2-MU; QFN-32-1EP_5x5mm_P0.5mm_EP3.1x3.1mm
U2: SIM7600E-H; IC_SIM7600E-H; PARTREV 1.01
U3: ADS1115IDGS; TSSOP-10_3x3mm_P0.5mm
U4: BQ29707DSET; SON50P150X150X80-6N
U5: MT3608; SOT-23-6
Y1: 16MHz; Crystal_AT310_D3.0mm_L10.0mm_Horizontal
Z1, Z2: PGB1010604; RV_Disc_D7mm_W3.4mm_P5mm

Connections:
GND: BATTERY1.N, C1.1, C2.1, C3.2, C4.1, C5.2, C6.1, C7.1, C8.2, C9.1, C11.1, C12.1, C13.2, D3.1 (K), J1.5 (GND), J2.4 (GND), J2.S1 (SHIELD), J2.S2 (SHIELD), J2.S3 (SHIELD), J2.S4 (SHIELD), J3.S1, J3.S2, J5.6, L1.1, Q1.4 (S), Q1.7 (S), R1.1, R1.2, R3.1, R8.2, R18.2, S1.1, S1.2, U1.28 (UGND), U2.1 (GND), U2.2 (GND), U2.5 (GND), U2.10 (GND), U2.14 (GND), U2.37 (GND), U2.40 (GND), U2.41 (GND), U2.43 (GND), U2.57 (GND), U2.58 (GND), U2.60 (GND), U2.61 (GND), U2.64 (GND), U2.65 (GND), U2.77 (GND), U2.78 (GND), U2.80 (GND), U2.81 (GND), U4.4 (VSS), U5.2 (GND)
MAIN_ANT: J3.1, U2.82 (MAIN_ANT)
unnamed: BATTERY1.P, C7.2, D1.1 (K), L2.1, R6.2, U5.4 (EN), U5.5 (IN)
unnamed: C1.2, R2.1, Y1.1
unnamed: C2.2, U1.2 (PC0/XTAL2), Y1.2
unnamed: C3.1, U1.27 (UCAP)
unnamed: C5.1, J5.5, RR1.1, S1.3, S1.4, U1.24 (PC1/~RESET)
unnamed: C6.2, R6.1, U4.5 (BAT)
unnamed: C8.1, R9.1, R10.1
unnamed: C10.1, R18.1, U2.3 (PWRKEY)
unnamed: C10.2, U2.4 (RESET)
unnamed: C13.1, R11.1, U2.15 (VDD_1V8)
unnamed: D2.2 (A), L2.2, U5.1 (SW)
unnamed: F1.2, U1.31 (UVCC)
unnamed: J4.2, U3.4 (AIN0)
unnamed: J4.3, U3.3 (GND)
unnamed: J5.1, U1.17 (PB3)
unnamed: J5.3, U1.15 (PB1)
unnamed: J5.4, U1.16 (PB2)
unnamed: J1.S1 (SHIELD), J1.S2 (SHIELD), J1.S3 (SHIELD), J1.S4 (SHIELD), J1.S5 (SHIELD), J1.S6 (SHIELD), L1.2, RU1.1, Z1.1
unnamed: Q1.1 (D), Q1.2 (D), Q1.5 (D), Q1.6 (D), Q1.8 (D), Q2.1 (D), Q2.2 (D), Q2.5 (D), Q2.6 (D), Q2.8 (D)
unnamed: Q1.3 (G), R3.2, U4.3 (DOUT)
unnamed: Q2.3 (G), R4.1, U4.2 (COUT)
unnamed: Q2.4 (S), Q2.7 (S), R4.2, R5.2
unnamed: Q3.2 (B), R12.2
unnamed: Q3.3 (C), R14.2, U2.68 (RXD)
unnamed: Q4.1 (E), R13.2, U2.71 (TXD)
unnamed: Q4.2 (B), R11.2, R13.1
unnamed: R2.2, U1.1 (XTAL1)
unnamed: R5.1, U4.6 (V-)
unnamed: R7.2, R8.1, U5.3 (FB)
unnamed: R12.1, R14.1
unnamed: R15.2, U2.17 (USIM_DATA)
unnamed: R16.2, U2.18 (USIM_RST)
unnamed: R17.2, U2.19 (USIM_CLK)
unnamed: R19.1, U3.10 (SCL)
unnamed: R20.1, U3.9 (SDA)
unnamed: RU1.2, U1.30 (D-)
unnamed: RU2.1, U1.29 (D+)
unnamed: RU2.2, Z2.1
unnamed: U1.3 (GND), U1.33 (GND)
unnamed: J1.2 (D-), Z1.2
unnamed: J1.3 (D+), Z2.2
RXA: Q4.3 (C), R10.2, U1.6 (PD0)
SCA: R20.2, U1.26 (PC4)
SCL: R19.2, U1.25 (PC5)
SIM_CLK: J2.3 (CLOCK), R17.1
SIM_DATA: J2.6 (I/O), R15.1
SIM_RST: J2.2 (RESET), R16.1
SIM_VDD: J2.1 (VCC), U2.20 (USIM_VDD)
TXA: Q3.1 (E), R9.2, U1.7 (PD1)
VBAT: C4.2, C9.2, C11.2, C12.2, D2.1 (K), D3.2 (A), F1.1, J4.1, J5.2, R7.1, RR1.2, U1.4 (VCC), U1.32 (AVCC), U2.38 (VBAT), U2.39 (VBAT), U2.62 (VBAT), U2.63 (VBAT), U3.8 (VDD)
VUSB: D1.2 (A), J1.1 (VBUS)

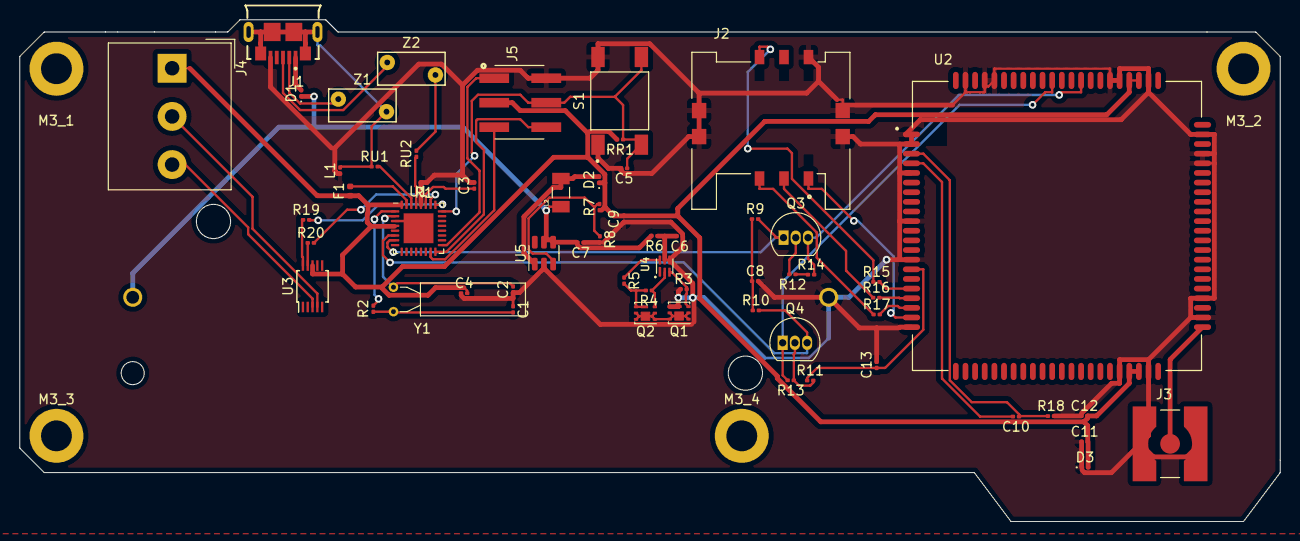
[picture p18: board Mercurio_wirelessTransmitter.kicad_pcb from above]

Board: 2 copper layers, 130.8 x 52.1 mm, 65 parts (1 on the bottom side), 53 nets.

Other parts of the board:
M3_1, M3_2, M3_3, M3_4: MountingHole_3.2mm_M3_DIN965_Pad

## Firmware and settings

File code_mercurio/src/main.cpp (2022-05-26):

#include <Arduino.h>
#include <Wire.h>
#include <SoftwareSerial.h>
#include <Adafruit_ADS1015.h>
#include <ArduinoLowPower.h>
 
Adafruit_ADS1115 ads;
const float multiplier = 0.1875F;
//This sets the parameters used by the ADS1115 library to properly receive the sensor's data.

SoftwareSerial mySerial(6,7);


String Publish = "sensorReading/publish"; //Publish Topic
String Subscribe = "sensorReading/subscribe"; //Subscribe Topic

void GSM_LTE_START(){

//This sets the cellphone provider. In this case, Claro BR is being used as an example.
mySerial.print("AT+CSTT=\"claro.com.br\",\"claro\",\"claro\"\r\n"); //APN name, username, password
  delay(1000);
  mySerial.print("AT+CIPMODE=0\r\n");
  delay(1000);
  mySerial.print("AT+CIICR\r\n");
  delay(5000);

}

void setup() 
{
  Serial.begin(9600);
  ads.setGain(GAIN_SIXTEEN);
  ads.begin();
  //This starts the I2C communication between the ADS1115 analog-digital converter and the microcontroller.

  mySerial.begin(9600);
  GSM_LTE_START();

  //AT commands sent to the GSM chip for client ID and server address setup. This will establish the communication from now on.
  mySerial.println("ATE0");
  delay(2000);
  mySerial.println("AT+CMQTTSTART"); //Initiating the MQTT connection
  delay(2000); 
  mySerial.println("AT+CMQTTACCQ=0,\"mercurioSensor1\""); //Informing the client ID
  delay(2000);
  mySerial.println("AT+CMQTTCONNECT=0,\"tcp://example.com:00000\",90,1"); //Server address to which the client will connect to
  delay(2000);

  //The delay times set above are for waiting for the data to be sent, but can be substituted by a verification code for AT confirmation codes.

  //SUBSCRIBE MESSAGE
  mySerial.println("AT+CMQTTSUBTOPIC=0,9,1"); //AT command for establishing the Subscribe topic's name 
  delay(2000);
  mySerial.println(Subscribe); //Topic's name
  delay(2000);
  mySerial.println("AT+CMQTTSUB=0,5,1,1"); //Sets the length of the message
  delay(2000);
  mySerial.println("START"); //Sends the message
  delay(2000);

}

void loop(){
  
  int16_t adc0;
  int16_t sensor_value;
  int wordCount = 0;
  bool dataTransmission = false;
 
  adc0 = ads.readADC_SingleEnded(0);
  sensor_value = adc0 * multiplier;
  //This converts the sensor value read by the 16-bit ADC (ADS1115)

  while(wordCount < 256000){
    mySerial.println("AT+CMQTTTOPIC=0,8"); //AT Command for Setting up the Publish Topic Name
    mySerial.println(Publish); //Topic's name
    mySerial.println("AT+CMQTTPAYLOAD=0,16"); //Payload length
    mySerial.println(sensor_value); //Payload message
    mySerial.println("AT+CMQTTPUB=0,1,60"); //Acknowledgment

    //Publishes a topic containing 1 sensor read cycle (16 bits in length).
    //After this loop is completed 256k times, the transmitter has completed the required 512kB of sensor data sent.

    wordCount++;
    dataTransmission = true;
  } 
  
  if(dataTransmission == true){
      LowPower.deepSleep(3600000);
      dataTransmission = false;

      //After the sensor data publishing loop ends, the microcontroller is sent into power saving mode for an hour.
  }
}

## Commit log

2022-05-18 Adicionada pasta component_lib contendo as bibliotecas de componentes.
    [CINTERION_PLS83-W.step]
2022-05-19 Adicionado diretorio do projeto KiCAD do Transmissor Sem Fio.
    [Mercurio_wirelessTransmitter.kicad_pcb, Mercurio_wirelessTransmitter.sch]
2022-05-20 Revisada biblioteca de componentes.
    [ATMEGA16U2-MUR--3DModel-STEP-56544.STEP, CINTERION_PLS83-W.step, Mercurio_wirelessTransmitter.kicad_pcb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]
2022-05-20 Alteracoes ao esquematico.
    [Mercurio_wirelessTransmitter.kicad_pcb, Mercurio_wirelessTransmitter.kicad_sch]
2022-05-20 Adicionados componentes para a biblioteca e atualizado o esquematico.
    [Mercurio_wirelessTransmitter.kicad_sch]
2022-05-22 Esquematico atualizado e lib de componentes atualizada
    [61000621121.step, 61000621121.stp, CONSMA001-SMD-G--3DModel-STEP-56544.STEP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]
2022-05-22 Atualizado esquematico e atualizadas as libs de componentes
2022-05-23 Finalizado esquematico, adicionado PDF do esquematico e atualizadas as libs de componentes
    [1043.step, 1048P--3DModel-STEP-56544.STEP, 1048P.step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]
2022-05-23 Atualizados labels de componentes e footprints atribuidos.
    [Mercurio_wirelessTransmitter.kicad_sch]
2022-05-24 Esquematico finalizado, PCB criada e organizada, lib atualizada.
    [1048P--3DModel-STEP-56544.STEP, 1048P.step, 5-1437565-0.step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]
2022-05-24 Finalizada a PCB 2D e 3D, documentado esquematico e vistas de PCB 2D e 3D
    [Mercurio_wirelessTransmitter.dsn, Mercurio_wirelessTransmitter.kicad_pcb, Mercurio_wirelessTransmitter1.dsn]
2022-05-24 Arquivos Spectra sobressalentes apagados e pasta docs renomeada.
    [Mercurio_wirelessTransmitter.dsn, Mercurio_wirelessTransmitter1.dsn]
2022-05-24 Criada tabela 'Bill of Materials' vazia
2022-05-25 Pastas renomeadas e codigo criado
    [1043.step, 5-1437565-0.step, 61000621121.step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]
2022-05-25 Add codigo de config GSM
2022-05-26 Finalizado BOM.md
